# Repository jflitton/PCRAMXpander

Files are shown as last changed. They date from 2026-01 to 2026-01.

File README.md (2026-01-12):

# PCRAMXpander

> **Note:** This project is currently untested. The first batch of boards has been ordered for testing.

An 8MB memory expansion card for the 16-bit ISA bus, designed as a modern alternative to the somewhat difficult to find ISA version of [IBM's Memory Expansion boards](https://www.ardent-tool.com/memory/IBM_Expansion.html#1_8MB).

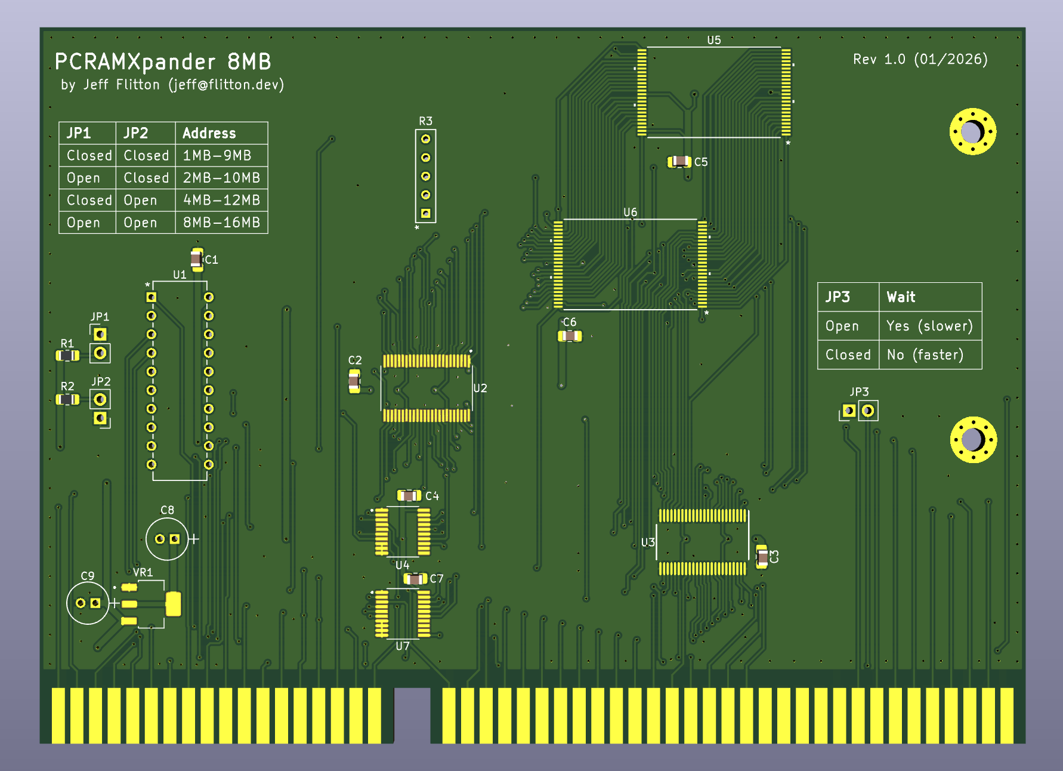
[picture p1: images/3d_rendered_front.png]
Rendered PCB (front)


This card should likely only be used in systems where the ISA bus is clocked at the same rate as the processor (often the case for 286-based systems).  While this board should work on faster 386 and 486-based systems, this board's memory will significantly underperform the motherboard-attached memory.

## Features

- **8MB total memory** using two 4MB SRAM chips (AS6C3216A)
- **Configurable base address** supporting systems with 1MB, 2MB, 4MB, or 8MB of existing memory
- **Zero wait state mode** for faster memory access on supported systems
- **Simple design** with address decoding handled by a single GAL (ATF16V8B)

## Configuration

### Memory Jumpers (JP1, JP2)

Configure the board's starting address based on your system's existing memory:

| Existing Memory | JP1 | JP2 | Memory Range |
|---|---|---|---|
| 1MB | Closed | Closed | 1MB – 9MB |
| 2MB | Open | Closed | 2MB – 10MB |
| 4MB | Closed | Open | 4MB – 12MB |
| 8MB | Open | Open | 8MB – 16MB |

> **Note:** Configurations with less than 1MB of existing memory are not currently supported.

### Zero Wait State Jumper (JP3)

Installing a jumper on JP3 enables zero wait state mode. This is **recommended** for systems that support it, as it significantly improves memory access performance.

## Theory of Operation

### Overview

The PCRAMXpander provides 8MB of additional memory to an ISA-bus system using two 4MB SRAM chips. A GAL (U1) handles address decoding, while buffer ICs manage the data and address buses.

### Address Decoding (U1 – ATF16V8B)

The GAL monitors the upper address lines (LA23–LA20) to determine which 1MB block is being accessed. Based on the jumper configuration (JP1, JP2), it calculates whether the requested address falls within the board's memory range.

The memory is split into two 4MB banks:
- **Low bank (U5):** First 4MB of the expansion range
- **High bank (U6):** Second 4MB of the expansion range

The GAL generates active-low chip select signals (`CS_LO`, `CS_HI`) for each bank. It also asserts:
- **MEMCS16:** Indicates 16-bit memory is present at this address
- **NOWS:** Signals zero wait state capability (directly from JP3 setting)

Both MEMCS16 and NOWS are active-low, open-collector outputs, allowing multiple ISA cards to share these signals.

### Bus Interface

| IC  | Function |
|-----|---|
| U2 (SN74LVCR16245ADGGR) | Bidirectional 16-bit data buffer between ISA bus and SRAM |
| U3 (SN74LVC16244ADGGR) | 16-bit address buffer (A1–A16) |
| U4 (SN74LVC16244A) | Additional address buffering |
| U7 (SN74LVC573APWR) | Address latch for upper address bits |

The data buffer (U2) is enabled by the `TRANS_EN` signal from the GAL whenever either SRAM chip is selected. Its direction is controlled by the ISA bus read/write signals.

### Power Supply

A 3.3V LDO regulator (VR1 – LDL1117S33R) provides power to the low-voltage SRAM and buffer ICs from the ISA bus 5V rail. Bypass capacitors ensure stable operation.

### Timing

When zero wait state mode is enabled (JP3 closed), the board signals to the host that no additional wait states are required for memory access. The AS6C3216A SRAM has a 55ns access time, which is fast enough for zero wait state operation on most ISA systems.

## License

This work is licensed under the [Creative Commons NonCommercial 4.0 International license](https://creativecommons.org/licenses/by-nc/4.0/).

## Authors

- [Jeff Flitton](mailto:jeff@flitton.dev) – Project creator

## Disclaimer

This project is provided as-is, without any express or implied warranty. By using, building, or modifying this hardware, you acknowledge that you do so at your own risk. The authors and contributors are not responsible for any damage, data loss, injury, or other consequences resulting from its use.

This project is a community-driven, open-hardware design intended for educational and hobbyist use. It is not affiliated with, endorsed by, or supported by IBM or any successor entities.

All trademarks are the property of their respective owners and are used here for descriptive and compatibility purposes only.

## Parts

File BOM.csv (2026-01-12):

Id | Designator | Footprint | Quantity | Designation | Supplier and ref
1 | U2 | SOP50P810X120-48N | 1 | SN74LVCR16245ADGGR
2 | C7,C1,C5,C2,C6,C4,C3 | C_0805_2012Metric_Pad1.18x1.45mm_HandSolder | 7 | .1 uF
3 | R2,R1 | R_0805_2012Metric_Pad1.20x1.40mm_HandSolder | 2 | 10k
4 | C8,C9 | CAP_PAN_5X11_PAN | 2 | 47uF
5 | VR1 | SOT230P700X180-4N | 1 | LDL1117S33R
6 | U3 | DGG0048A_N | 1 | SN74LVC16244ADGGR
7 | J1 | BUS_AT | 1 | Bus_ISA_16bit
8 | U5,U6 | TSOP-I-48_12X20_ALL | 2 | AS6C3216A-55TIN
9 | JP2 | PinHeader_1x02_P2.54mm_Vertical | 1 | MB Memory 2
10 | JP3 | PinHeader_1x02_P2.54mm_Vertical | 1 | 0WS/Turbo
11 | JP1 | PinHeader_1x02_P2.54mm_Vertical | 1 | MB Memory 1
12 | U7 | SOP65P640X120-20N | 1 | SN74LVC573APWR
13 | R3 | CSC05_VIS | 1 | 10k
14 | U4 | SOP65P640X120-20N | 1 | SN74LVC16244A
15 | U1 | 20P3_ATM | 1 | ATF16V8B-15PU

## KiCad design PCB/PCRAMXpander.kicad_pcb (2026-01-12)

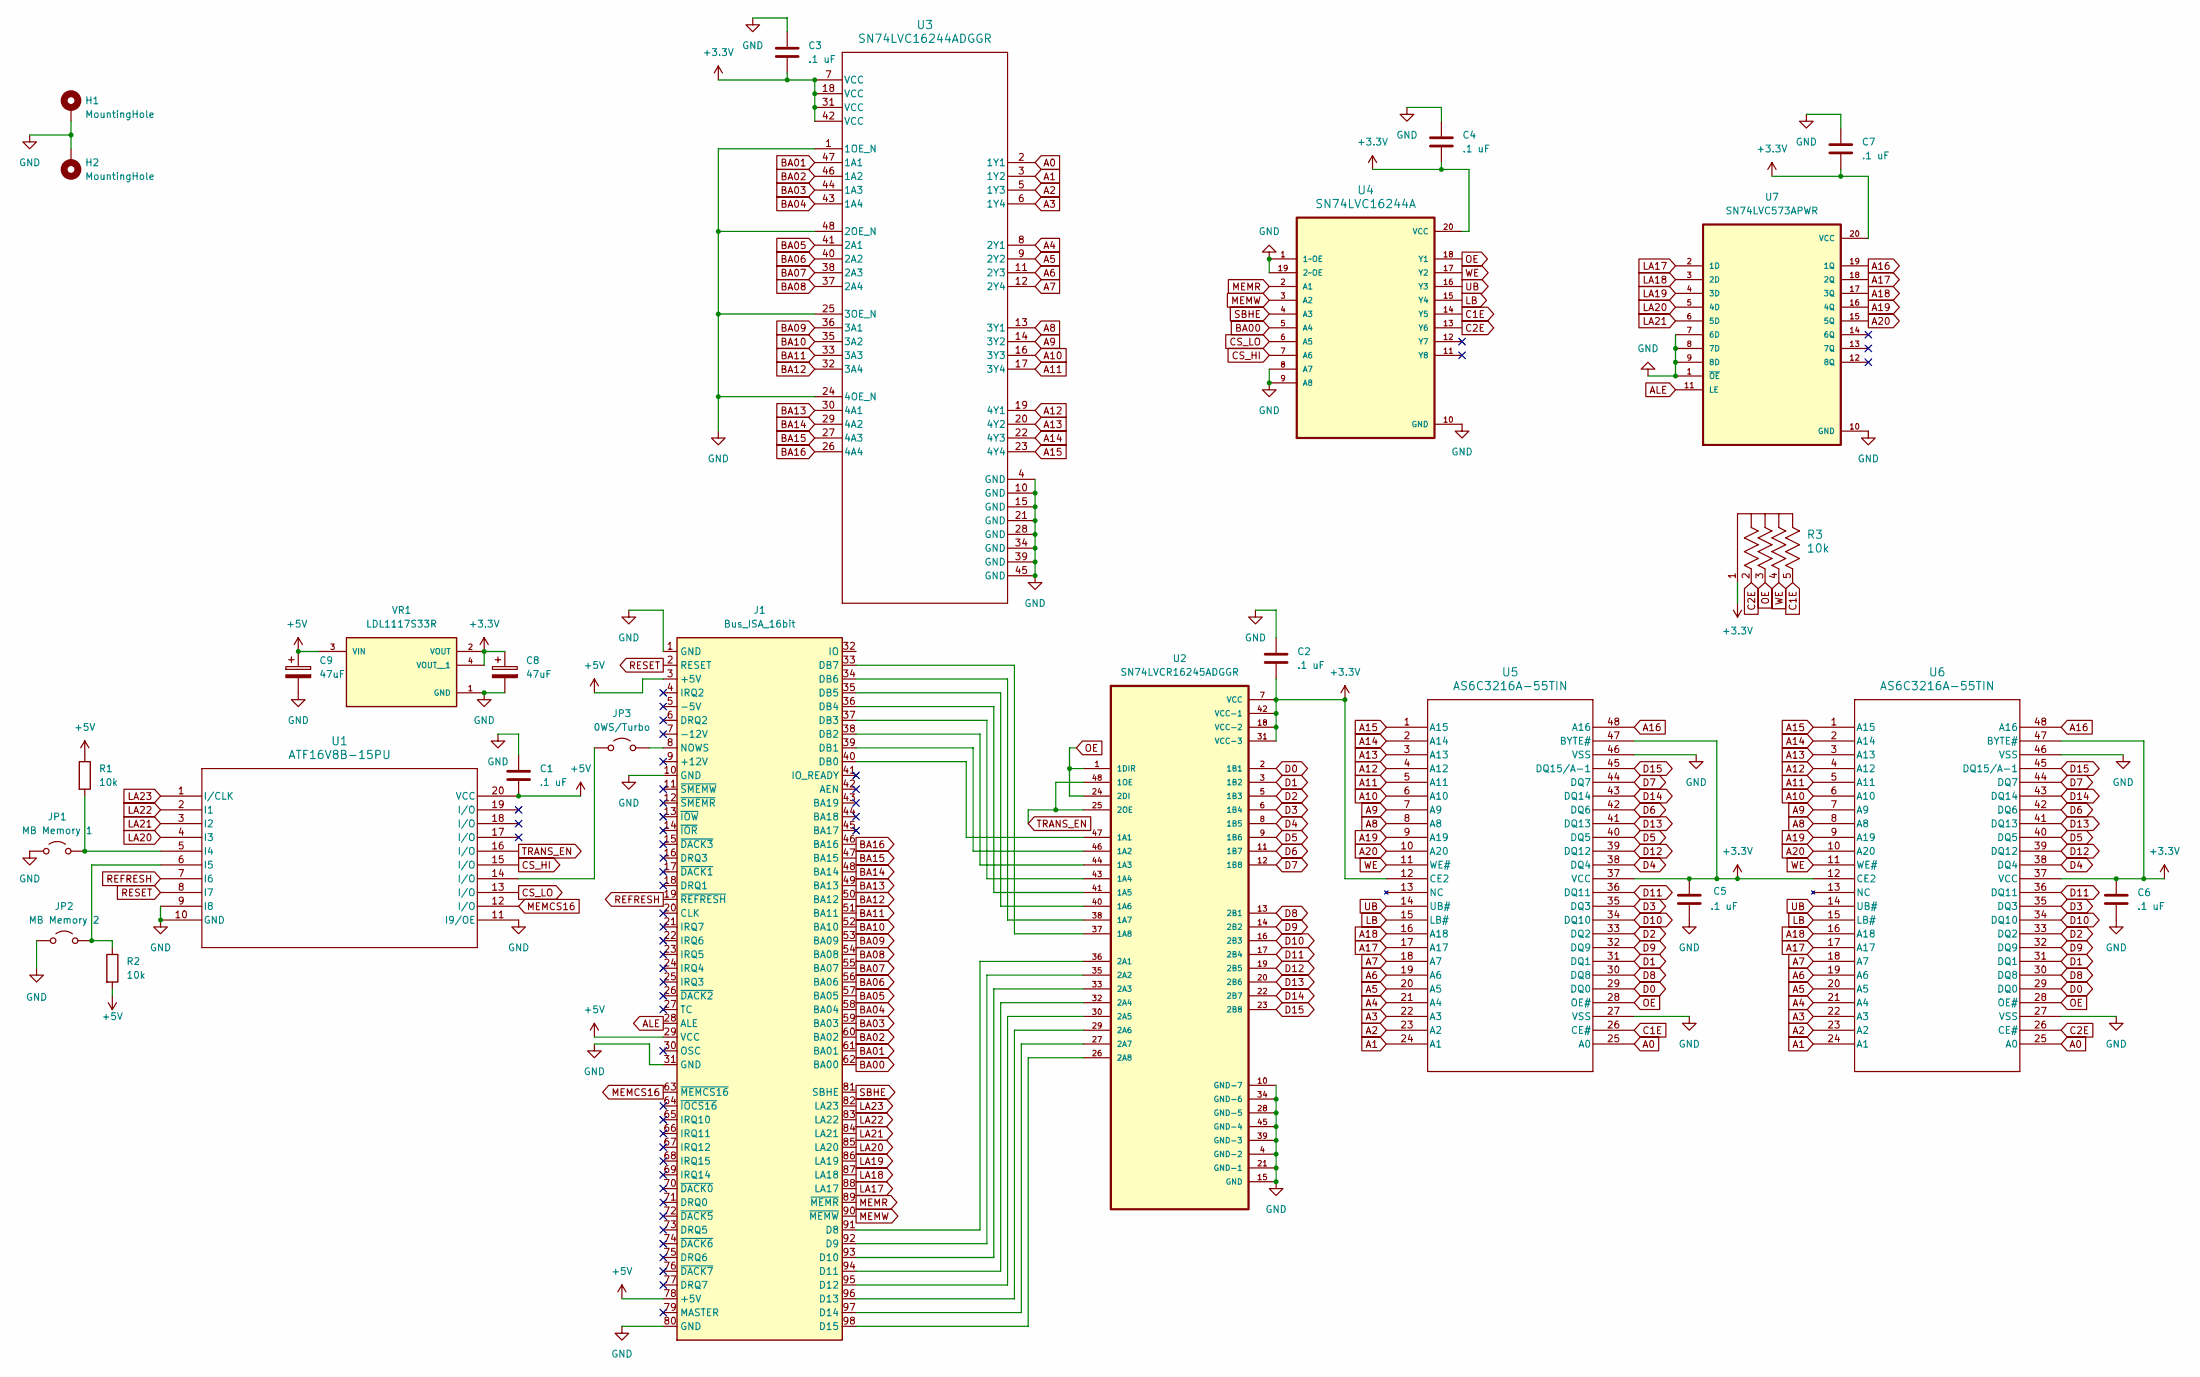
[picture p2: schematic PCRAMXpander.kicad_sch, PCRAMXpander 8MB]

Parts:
C1, C2, C3, C4, C5, C6, C7: .1 uF; C_0805_2012Metric_Pad1.18x1.45mm_HandSolder
C8, C9: 47uF; CAP_PAN_5X11_PAN
H1, H2: MountingHole; MountingHole_3.2mm_M3_Pad_Via
J1: Bus_ISA_16bit; BUS_AT
JP1: MB Memory 1; PinHeader_1x02_P2.54mm_Vertical
JP2: MB Memory 2; PinHeader_1x02_P2.54mm_Vertical
JP3: 0WS/Turbo; PinHeader_1x02_P2.54mm_Vertical
R1, R2: 10k; R_0805_2012Metric_Pad1.20x1.40mm_HandSolder
R3: 10k; CSC05_VIS
U1: ATF16V8B-15PU; 20P3_ATM
U2: SN74LVCR16245ADGGR; SOP50P810X120-48N
U3: SN74LVC16244ADGGR; DGG0048A_N
U4: SN74LVC16244A; SOP65P640X120-20N
U5, U6: AS6C3216A-55TIN; TSOP-I-48_12X20_ALL
U7: SN74LVC573APWR; SOP65P640X120-20N
VR1: LDL1117S33R; SOT230P700X180-4N; PARTREV 7

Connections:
+3.3V: C2.2, C3.2, C4.2, C5.1, C6.1, C7.2, C8.1, R3.1, U2.7 (VCC), U2.18 (VCC-2), U2.31 (VCC-3), U2.42 (VCC-1), U3.7 (VCC), U3.18 (VCC), U3.31 (VCC), U3.42 (VCC), U4.20 (VCC), U5.12 (CE2), U5.37 (VCC), U5.47 (BYTE#), U6.12 (CE2), U6.37 (VCC), U6.47 (BYTE#), U7.20 (VCC), VR1.2 (VOUT), VR1.4 (VOUT__1)
+5V: C1.2, C9.1, J1.3 (+5V), J1.29 (VCC), J1.78 (+5V), R1.1, R2.2, U1.20 (VCC), VR1.3 (VIN)
A0: U3.2 (1Y1), U5.25 (A0), U6.25 (A0)
A1: U3.3 (1Y2), U5.24 (A1), U6.24 (A1)
A2: U3.5 (1Y3), U5.23 (A2), U6.23 (A2)
A3: U3.6 (1Y4), U5.22 (A3), U6.22 (A3)
A4: U3.8 (2Y1), U5.21 (A4), U6.21 (A4)
A5: U3.9 (2Y2), U5.20 (A5), U6.20 (A5)
A6: U3.11 (2Y3), U5.19 (A6), U6.19 (A6)
A7: U3.12 (2Y4), U5.18 (A7), U6.18 (A7)
A8: U3.13 (3Y1), U5.8 (A8), U6.8 (A8)
A9: U3.14 (3Y2), U5.7 (A9), U6.7 (A9)
A10: U3.16 (3Y3), U5.6 (A10), U6.6 (A10)
A11: U3.17 (3Y4), U5.5 (A11), U6.5 (A11)
A12: U3.19 (4Y1), U5.4 (A12), U6.4 (A12)
A13: U3.20 (4Y2), U5.3 (A13), U6.3 (A13)
A14: U3.22 (4Y3), U5.2 (A14), U6.2 (A14)
A15: U3.23 (4Y4), U5.1 (A15), U6.1 (A15)
A16: U5.48 (A16), U6.48 (A16), U7.19 (1Q)
A17: U5.17 (A17), U6.17 (A17), U7.18 (2Q)
A18: U5.16 (A18), U6.16 (A18), U7.17 (3Q)
A19: U5.9 (A19), U6.9 (A19), U7.16 (4Q)
A20: U5.10 (A20), U6.10 (A20), U7.15 (5Q)
ALE: J1.28 (ALE), U7.11 (LE)
BA00: J1.62 (BA00), U4.5 (A4)
BA01: J1.61 (BA01), U3.47 (1A1)
BA02: J1.60 (BA02), U3.46 (1A2)
BA03: J1.59 (BA03), U3.44 (1A3)
BA04: J1.58 (BA04), U3.43 (1A4)
BA05: J1.57 (BA05), U3.41 (2A1)
BA06: J1.56 (BA06), U3.40 (2A2)
BA07: J1.55 (BA07), U3.38 (2A3)
BA08: J1.54 (BA08), U3.37 (2A4)
BA09: J1.53 (BA09), U3.36 (3A1)
BA10: J1.52 (BA10), U3.35 (3A2)
BA11: J1.51 (BA11), U3.33 (3A3)
BA12: J1.50 (BA12), U3.32 (3A4)
BA13: J1.49 (BA13), U3.30 (4A1)
BA14: J1.48 (BA14), U3.29 (4A2)
BA15: J1.47 (BA15), U3.27 (4A3)
BA16: J1.46 (BA16), U3.26 (4A4)
C1E: R3.5, U4.14 (Y5), U5.26 (CE#)
C2E: R3.2, U4.13 (Y6), U6.26 (CE#)
CS_HI: U1.15 (I/O), U4.7 (A6)
CS_LO: U1.13 (I/O), U4.6 (A5)
D0: U2.2 (1B1), U5.29 (DQ0), U6.29 (DQ0)
D1: U2.3 (1B2), U5.31 (DQ1), U6.31 (DQ1)
D2: U2.5 (1B3), U5.33 (DQ2), U6.33 (DQ2)
D3: U2.6 (1B4), U5.35 (DQ3), U6.35 (DQ3)
D4: U2.8 (1B5), U5.38 (DQ4), U6.38 (DQ4)
D5: U2.9 (1B6), U5.40 (DQ5), U6.40 (DQ5)
D6: U2.11 (1B7), U5.42 (DQ6), U6.42 (DQ6)
D7: U2.12 (1B8), U5.44 (DQ7), U6.44 (DQ7)
D8: U2.13 (2B1), U5.30 (DQ8), U6.30 (DQ8)
D9: U2.14 (2B2), U5.32 (DQ9), U6.32 (DQ9)
D10: U2.16 (2B3), U5.34 (DQ10), U6.34 (DQ10)
D11: U2.17 (2B4), U5.36 (DQ11), U6.36 (DQ11)
D12: U2.19 (2B5), U5.39 (DQ12), U6.39 (DQ12)
D13: U2.20 (2B6), U5.41 (DQ13), U6.41 (DQ13)
D14: U2.22 (2B7), U5.43 (DQ14), U6.43 (DQ14)
D15: U2.23 (2B8), U5.45 (DQ15/A-1), U6.45 (DQ15/A-1)
GND: C1.1, C2.1, C3.1, C4.1, C5.2, C6.2, C7.1, C8.2, C9.2, H1.1, H2.1, J1.1 (GND), J1.10 (GND), J1.31 (GND), J1.80 (GND), JP1.1 (A), JP2.1 (A), U1.9 (I8), U1.10 (GND), U1.11 (I9/OE), U2.4 (GND-2), U2.10 (GND-7), U2.15 (GND), U2.21 (GND-1), U2.28 (GND-5), U2.34 (GND-6), U2.39 (GND-3), U2.45 (GND-4), U3.1 (1OE_N), U3.4 (GND), U3.10 (GND), U3.15 (GND), U3.21 (GND), U3.24 (4OE_N), U3.25 (3OE_N), U3.28 (GND), U3.34 (GND), U3.39 (GND), U3.45 (GND), U3.48 (2OE_N), U4.1 (1~OE), U4.8 (A7), U4.9 (A8), U4.10 (GND), U4.19 (2~OE), U5.27 (VSS), U5.46 (VSS), U6.27 (VSS), U6.46 (VSS), U7.1 (~OE), U7.7 (6D), U7.8 (7D), U7.9 (8D), U7.10 (GND), VR1.1 (GND)
LA17: J1.88 (LA17), U7.2 (1D)
LA18: J1.87 (LA18), U7.3 (2D)
LA19: J1.86 (LA19), U7.4 (3D)
LA20: J1.85 (LA20), U1.4 (I3), U7.5 (4D)
LA21: J1.84 (LA21), U1.3 (I2), U7.6 (5D)
LA22: J1.83 (LA22), U1.2 (I1)
LA23: J1.82 (LA23), U1.1 (I/CLK)
LB: U4.15 (Y4), U5.15 (LB#), U6.15 (LB#)
MEMCS16: J1.63 (~MEMCS16), U1.12 (I/O)
MEMR: J1.89 (~MEMR), U4.2 (A1)
MEMW: J1.90 (~MEMW), U4.3 (A2)
unnamed: J1.91 (D8), U2.36 (2A1)
unnamed: J1.92 (D9), U2.35 (2A2)
unnamed: J1.93 (D10), U2.33 (2A3)
unnamed: J1.94 (D11), U2.32 (2A4)
unnamed: J1.95 (D12), U2.30 (2A5)
unnamed: J1.96 (D13), U2.29 (2A6)
unnamed: J1.97 (D14), U2.27 (2A7)
unnamed: J1.98 (D15), U2.26 (2A8)
unnamed: J1.40 (DB0), U2.47 (1A1)
unnamed: J1.39 (DB1), U2.46 (1A2)
unnamed: J1.38 (DB2), U2.44 (1A3)
unnamed: J1.37 (DB3), U2.43 (1A4)
unnamed: J1.36 (DB4), U2.41 (1A5)
unnamed: J1.35 (DB5), U2.40 (1A6)
unnamed: J1.34 (DB6), U2.38 (1A7)
unnamed: J1.33 (DB7), U2.37 (1A8)
unnamed: J1.8 (NOWS), JP3.2 (B)
unnamed: JP1.2 (B), R1.2, U1.5 (I4)
unnamed: JP2.2 (B), R2.1, U1.6 (I5)
unnamed: JP3.1 (A), U1.14 (I/O)
OE: R3.3, U2.1 (1DIR), U2.24 (2DI), U4.18 (Y1), U5.28 (OE#), U6.28 (OE#)
REFRESH: J1.19 (~REFRESH), U1.7 (I6)
RESET: J1.2 (RESET), U1.8 (I7)
SBHE: J1.81 (SBHE), U4.4 (A3)
TRANS_EN: U1.16 (I/O), U2.25 (2OE), U2.48 (1OE)
UB: U4.16 (Y3), U5.14 (UB#), U6.14 (UB#)
WE: R3.4, U4.17 (Y2), U5.11 (WE#), U6.11 (WE#)

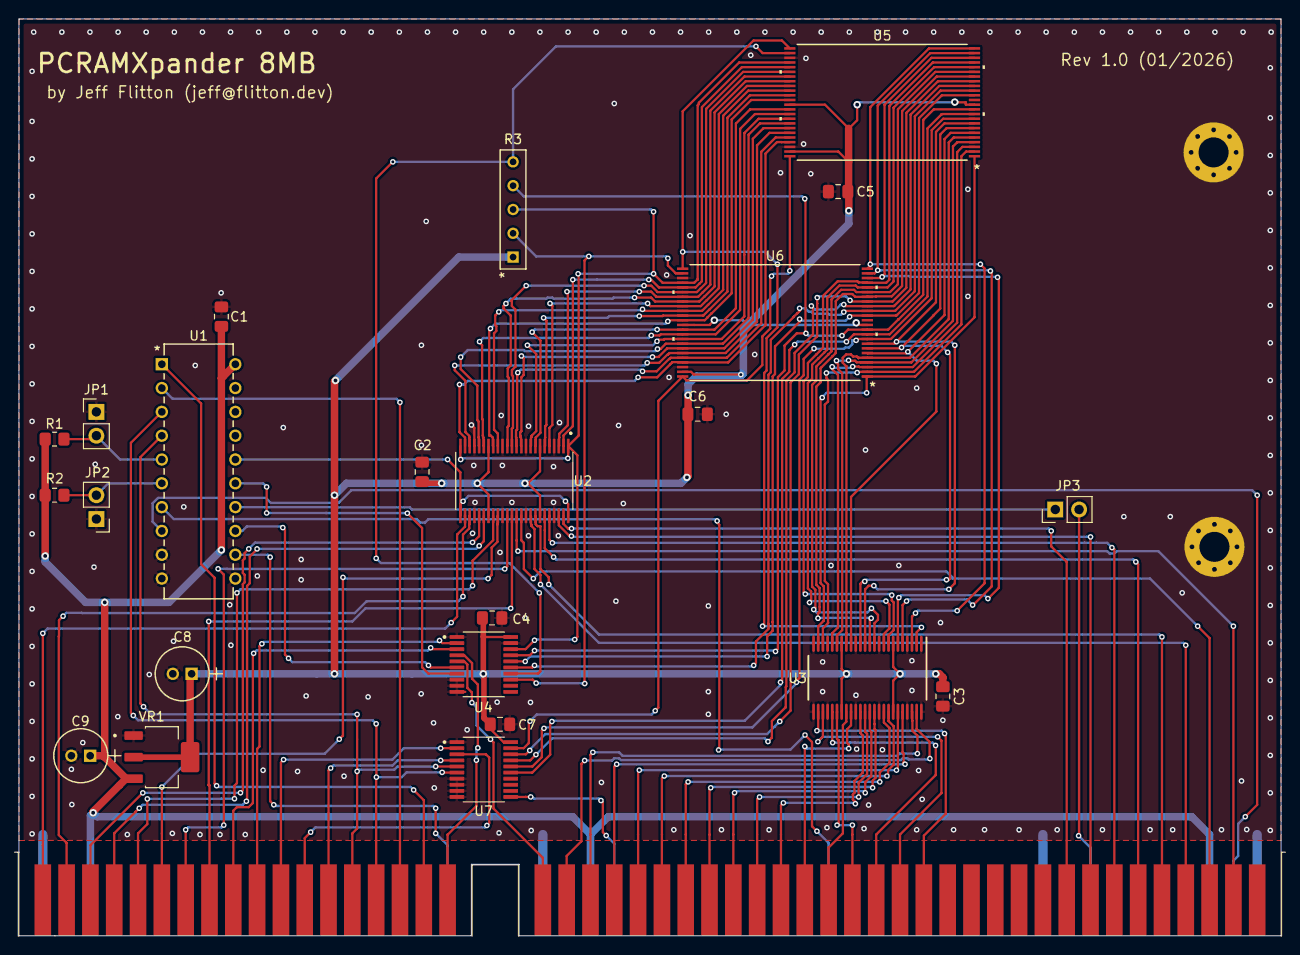
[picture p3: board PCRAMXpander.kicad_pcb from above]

Board: 2 copper layers, 134.6 x 97.8 mm, 26 parts (0 on the bottom side), 100 nets.

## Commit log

2026-01-01 Symbol libraries
    [PCRAMXpander.kicad_pcb, PCRAMXpander.kicad_sch]
2026-01-01 Switching to 245 w/ built-in resistors
    [PCRAMXpander.kicad_sch]
2026-01-02 Routing has begun
    [PCRAMXpander.kicad_pcb, PCRAMXpander.kicad_sch]
2026-01-03 Playing with routing a bit more
    [PCRAMXpander.kicad_pcb, PCRAMXpander.kicad_sch]
2026-01-03 Power routing only
    [PCRAMXpander.kicad_pcb]
2026-01-03 Potentially improved chip orientation
    [PCRAMXpander.kicad_pcb]
2026-01-03 manual routing of U3 right side
    [PCRAMXpander.kicad_pcb, freerouting.dsn]
2026-01-03 More manual routing
    [PCRAMXpander.kicad_pcb, freerouting.dsn]
2026-01-03 Moving U3 for more routing space
    [PCRAMXpander.kicad_pcb]
2026-01-04 Ram wired up
    [PCRAMXpander.kicad_pcb]
2026-01-04 5V done
    [PCRAMXpander.kicad_pcb]
2026-01-04 5v refinement
    [PCRAMXpander.kicad_pcb]
2026-01-04 SIP5 resistor pack
    [PCRAMXpander.kicad_pcb, PCRAMXpander.kicad_sch]
2026-01-04 Power refinement, ISA fingers
    [PCRAMXpander.kicad_pcb]
2026-01-04 Power refinement
    [PCRAMXpander.kicad_pcb]
2026-01-04 U6 routing
    [PCRAMXpander.kicad_pcb, PCRAMXpander.kicad_sch]
2026-01-05 Memory chips routed
    [PCRAMXpander.kicad_pcb, freerouting.dsn, temp-freerouting.dsn]
2026-01-05 Low data lines routed
    [PCRAMXpander.kicad_pcb]
2026-01-05 GAL and U4 routes
    [PCRAMXpander.kicad_pcb]
2026-01-05 All traces routed
    [PCRAMXpander.kicad_pcb]
2026-01-11 Transparent latch for high address lines
    [PCRAMXpander-B_Cu.gbr, PCRAMXpander-B_Mask.gbr, PCRAMXpander-B_Paste.gbr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]
2026-01-11 Revert "More manual routing"
    This reverts commit 0982fc74f345ec59384cba768510721dd6743d85.
    [PCRAMXpander.kicad_pcb]
2026-01-11 Revert "More manual routing"
    This reverts commit 1ef752c8dd37f4f521128f7022dea4d2c55a3ae6.
    [PCRAMXpander.kicad_pcb]
2026-01-11 Revert "More manual routing"
    This reverts commit 8fc89334eef3b822060e9ccc43876c88ada5381e.
    [PCRAMXpander.kicad_pcb, freerouting.dsn]
2026-01-11 Revert "More manual routing"
    This reverts commit 4701405ffdf181303b86cdb3b1250737cb80df36.
    [PCRAMXpander.kicad_pcb, freerouting.dsn]
2026-01-11 Revert "More manual routing"
    This reverts commit 8a1b72b23a01502d9d5028c2d37e0cfdb243fa78.
    [PCRAMXpander.kicad_pcb, freerouting.dsn]
2026-01-11 Revert "More manual routing"
    This reverts commit 646e4b39c57eedcae7559b9f3577459cb52bf620.
    [PCRAMXpander.kicad_pcb, freerouting.dsn]
2026-01-11 Revert "More manual routing"
    This reverts commit eb176bf1cf606b5faa7e563e33fd253a07104509.
    [PCRAMXpander.kicad_pcb]
2026-01-11 Revert "More manual routing"
    This reverts commit ad645bdee1b61d8c4c4095e91a6cf0d337db442c.
    [PCRAMXpander.kicad_pcb]
2026-01-11 Revert "More manual routing"
    This reverts commit b921debae46f28068d9de22bc133656cc87b6f20.
    [PCRAMXpander.kicad_pcb]
2026-01-11 Revert "More manual routing"
    This reverts commit 47449c23b7240c85fd4465f78316c60ac3030f38.
    [PCRAMXpander.kicad_pcb, PCRAMXpander.kicad_sch]
2026-01-11 Silkscreen updates, reset line wired
    [PCRAMXpander-B_Cu.gbr, PCRAMXpander-B_Mask.gbr, PCRAMXpander-B_Paste.gbr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]
2026-01-11 Adding BOM, a little trace cleanup
    [BOM.csv, PCRAMXpander.kicad_pcb]
2026-01-11 Added mounting holes
    [BOM.csv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]
2026-01-11 Moving some labels
    [PCRAMXpander-B_Cu.gbr, PCRAMXpander-B_Mask.gbr, PCRAMXpander-B_Paste.gbr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]
2026-01-12 Fixing BOM
    [BOM.csv]
2026-01-12 Adding rendered card image
    [PCRAMXpander.kicad_pcb]
2026-01-29 Fixing value
    [PCRAMXpander.kicad_sch]
